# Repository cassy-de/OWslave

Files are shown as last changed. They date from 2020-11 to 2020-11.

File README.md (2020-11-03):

# OWslave
OneWire Slave DIY Module

<p align="center">
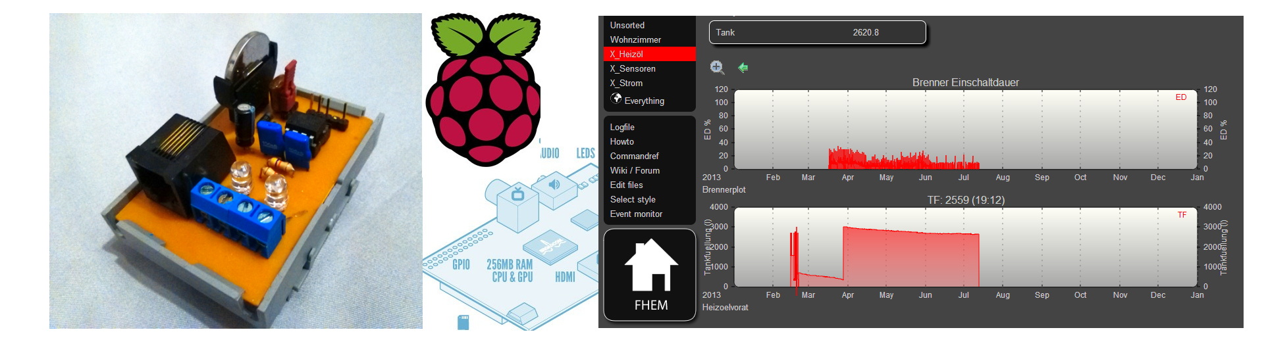
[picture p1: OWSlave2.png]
  
</p>

 ATtiny 25, intern 8MHz
 PB4 als Autoincrement-Counters.A, low-aktiv (Pegel), alle 10 Sekunden ein Count
 PB3 ist abgehängt von Counters.B, dafür machen PB0 und PB1 den I2C-Bus für den SRF02 auf 

 lfuse 62
 hfuse DF
 efuse FF

<p align="center">
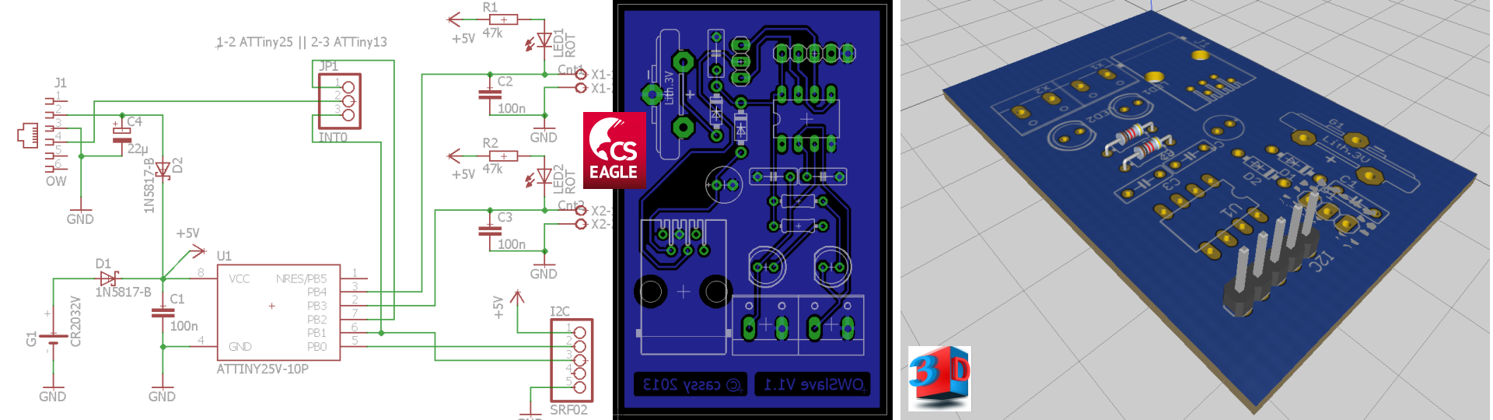
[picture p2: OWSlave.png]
  
</p>

-------------
Zur Firmware:
Die I2C-Libs werden zusätzlich eingebunden, die I2C-Adresse des SRF02 ist fix 0xE0, er wird mit cm als Rückgabewert programmiert. Die Interrupts von
PB3 und PB4 sind disabled, denn PB3 (Counters.B) wird nicht benötigt (ist Messwert des SRF02), und PB4 (Counters.A) wird in der main{} gepollt, dann 10 Sekunden Pause und wieder von vorne, also eigentlich straightforward gelöst. Die I2C-Routine sind atomar gesetzt, dass hier kein IRQ dazwischenfunkt. Somit kann es passieren, dass u.U. der OWFS/OWserver das Device nicht erreicht. Aber lieber in FHEM einen alten Messwert fortschreiben, als einen definitiv falschen eintragen. Achso, in der ISR sind die beiden Increments gelöscht. Und die Extra-Inits für den ATtiny2313 habe ich gleich aus dem Quellcode geschmissen, somit liest es sich etwas leichter.

-------------
OWServer Anzeige:

address 1DA2D984000102F3

counters.ALL 5, 136

counters.A 5

counters.B 136

crc8 F3

family 1D

id A2D984000102

Passt alles soweit, der Brenner lief testweise 55 Sekunden (counters.A ist 5), und bis zum Heizöl sind es  136 cm.

Viel Spass beim Testen.

cassy

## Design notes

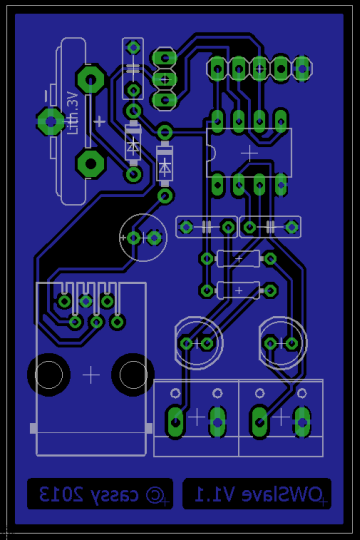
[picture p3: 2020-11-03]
Eagle/Board.PNG

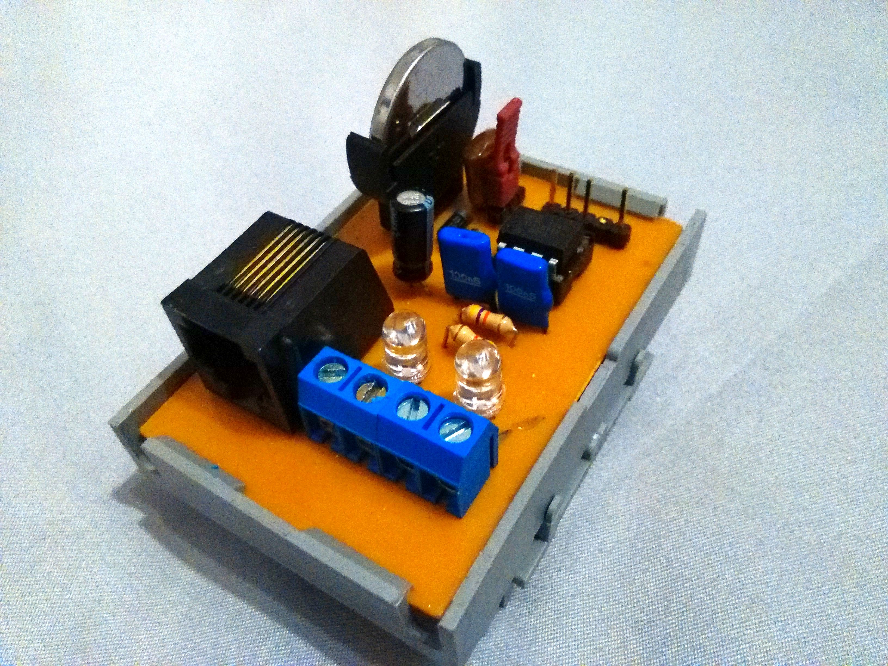
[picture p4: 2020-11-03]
Eagle/Board.jpg

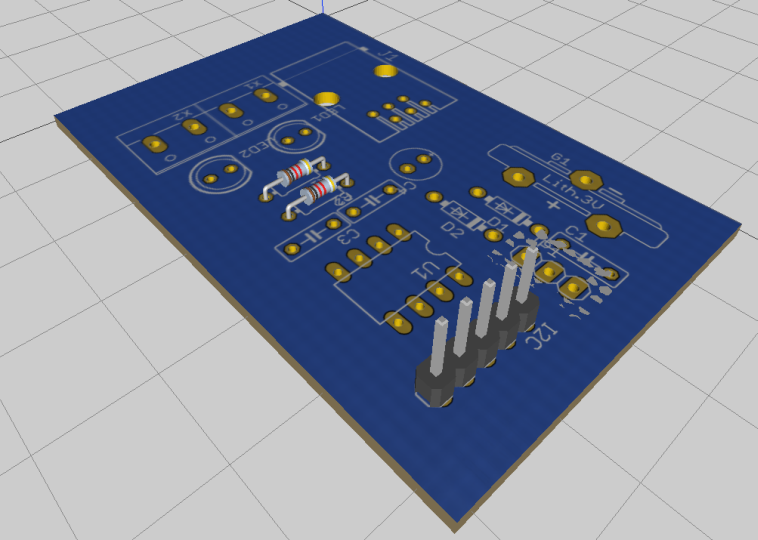
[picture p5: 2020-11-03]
Eagle/Board-3D.PNG

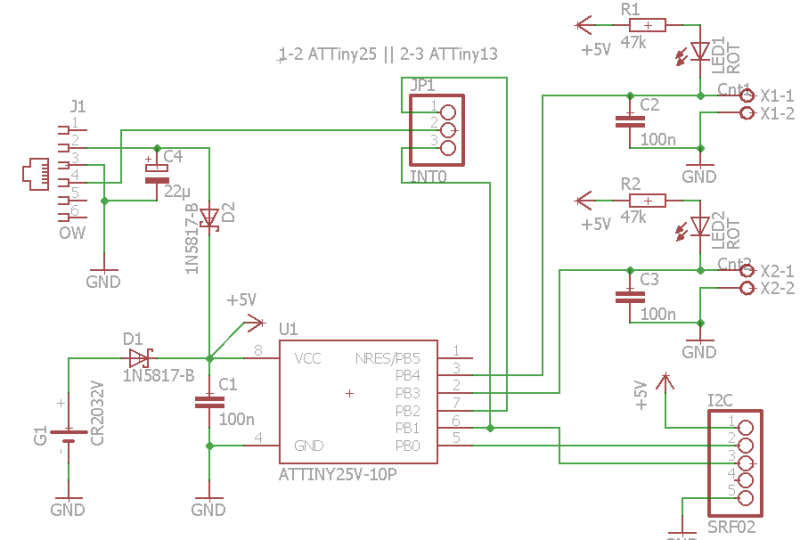
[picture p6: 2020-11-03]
Eagle/Schaltplan.PNG

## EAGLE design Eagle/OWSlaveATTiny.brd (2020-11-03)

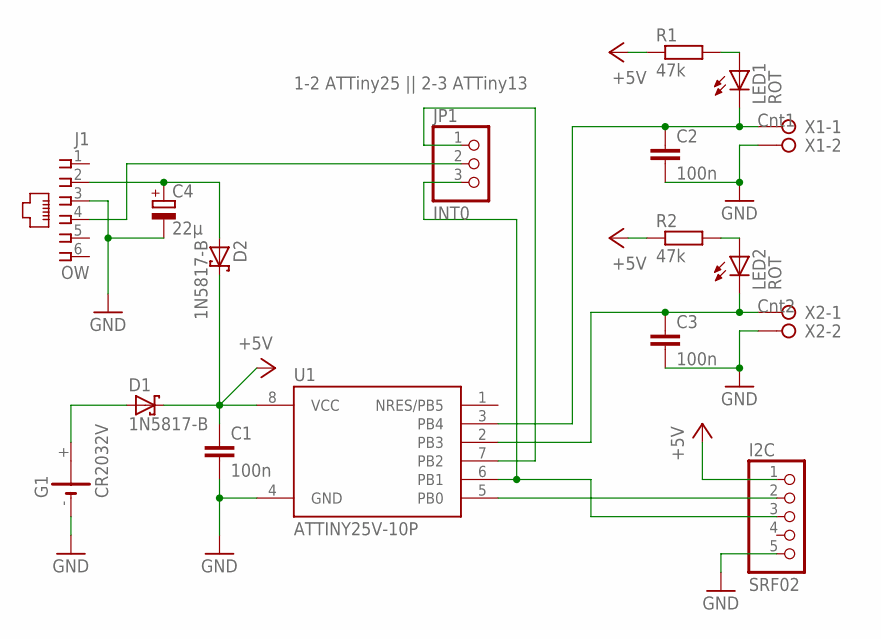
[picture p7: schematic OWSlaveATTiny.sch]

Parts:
C1, C2, C3: 100n; C050-025X075
C4: 22µ; E2,5-6E
D1, D2: 1N5817-B; DO41-7.6
G1: CR2032V
I2C: SRF02; 1X05
J1: OW; 520250-3
JP1: INT0; 1X03
LED1, LED2: ROT; LED5MM
R1, R2: 47k; 0204/7
U1: ATTINY25V-10P; PDIP08_300MIL
X1: Cnt1; W237-132
X2: Cnt2; W237-132

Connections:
+5V: C1.1, D1.C, D2.C, I2C.1, R1.1, R2.1, U1.8 (VCC)
GND: C1.2, C2.2, C3.2, C4.-, G1.-, I2C.5, J1.3, U1.4 (GND), X1.2, X2.2
unnamed: LED1.A, R1.2
unnamed: D1.A, G1.+
unnamed: J1.4, JP1.2
unnamed: C2.1, LED1.K (C), U1.3 (PB4), X1.1
unnamed: C3.1, LED2.K (C), U1.2 (PB3), X2.1
unnamed: I2C.3, JP1.3, U1.6 (PB1)
unnamed: JP1.1, U1.7 (PB2)
unnamed: I2C.2, U1.5 (PB0)
unnamed: C4.+, D2.A, J1.2
unnamed: LED2.A, R2.2

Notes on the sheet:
1-2 ATTiny25 || 2-3 ATTiny13

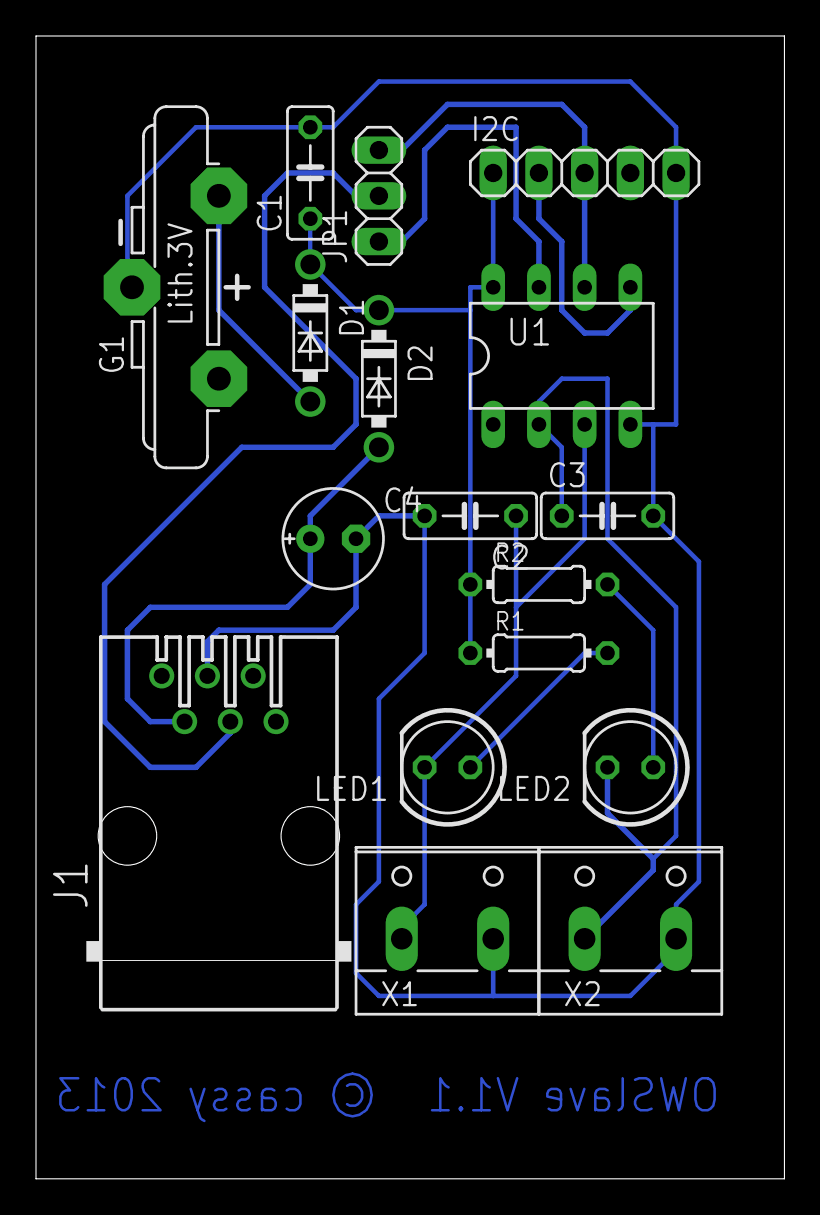
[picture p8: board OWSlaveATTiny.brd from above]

Board: 2 copper layers, 41.6 x 63.5 mm, 17 parts (0 on the bottom side), 12 nets.

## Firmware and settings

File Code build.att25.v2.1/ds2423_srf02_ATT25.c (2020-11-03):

//owdevice - A small 1-Wire emulator for AVR Microcontroller
//
//Copyright (C) 2012  Tobias Mueller mail (at) tobynet.de
//Modification by Christoph A. Straessle 2013 (s. below)
//
//
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
//
//VERSION 1.2 DS2423  for ATTINY2313 and ATTINY25
//Version 2.0 als DS2423 fuer ATtiny25 mit I2C-libs und Anbindung an SRF02 als counters.B
//Version 2.1 als DS2423 fuer ATtiny25 mit Sekunden-Zaehler counter.A, I2C-libs und Anbindung an SRF02 als counters.B
// PB0 - SDA
// PB1 - SCL
// PB2 - OW <- INT0 fixed
// PB3 - ( counters.A) als Gate fuer Counter.A-Sekundenimpulse 
// PB4 - ( counters.B) unused, nun als Ausgang fuer die Impuls-LED

#include <avr/io.h>
#include <avr/interrupt.h>
#define F_CPU 8000000UL
#include <util/delay.h>
#include "i2cmaster.h"

#define SRF02_ADDRESS 0xE0

/* SRF02 - Get Distance in cm. */
unsigned int read_cm(unsigned char address)
{
	unsigned char lowbyte,highbyte;
	unsigned int distance;

	i2c_start_wait(address+I2C_WRITE);
	while (i2c_write(0));
	while (i2c_write(81));
	i2c_stop();

	i2c_start_wait(address+I2C_WRITE);
	while (i2c_write(2));
	i2c_stop();

	_delay_ms(65);
	i2c_start_wait(address+I2C_READ);
	highbyte = i2c_readAck();
	lowbyte = i2c_readNak();
	distance = (highbyte*256)+lowbyte;
	i2c_stop();

	return distance;
} 


#ifdef __AVR_ATtiny25__ 

//LED Pin
#define LED_PORT PORTB //LED Port
#define LED_PIN PINB //LED Pin as number
#define LED_PORTN (1<<PINB3)  //Pin as bit in registers
#define LED_PINN (1<<PINB3)
#define LED_DDR DDRB  //pin direction register
#define LED_EIN OW_DDR|=OW_PINN;OW_PORT&=~OW_PORTN;  //set LED line to low
#define LED_AUS {OW_DDR&=~OW_PINN;}  //set LED pin as input -> LED aus

// OW_PORT Pin 7  - PB2
//OW Pin
#define OW_PORT PORTB //1 Wire Port
#define OW_PIN PINB //1 Wire Pin as number
#define OW_PORTN (1<<PINB2)  //Pin as bit in registers
#define OW_PINN (1<<PINB2)
#define OW_DDR DDRB  //pin direction register
#define SET_LOW OW_DDR|=OW_PINN;OW_PORT&=~OW_PORTN;  //set 1-Wire line to low
#define RESET_LOW {OW_DDR&=~OW_PINN;}  //set 1-Wire pin as input
//Pin interrupt	
#define EN_OWINT {GIMSK|=(1<<INT0);GIFR|=(1<<INTF0);}  //enable interrupt 
#define DIS_OWINT  GIMSK&=~(1<<INT0);  //disable interrupt
#define SET_RISING MCUCR=(1<<ISC01)|(1<<ISC00);  //set interrupt at rising edge
#define SET_FALLING MCUCR=(1<<ISC01); //set interrupt at falling edge
#define CHK_INT_EN (GIMSK&(1<<INT0))==(1<<INT0) //test if interrupt enabled
#define PIN_INT ISR(INT0_vect)  // the interrupt service routine
//Timer Interrupt
#define EN_TIMER {TIMSK |= (1<<TOIE0); TIFR|=(1<<TOV0);} //enable timer interrupt
#define DIS_TIMER TIMSK  &= ~(1<<TOIE0); // disable timer interrupt
#define TCNT_REG TCNT0  //register of timer-counter
#define TIMER_INT ISR(TIM0_OVF_vect) //the timer interrupt service routine


#define OWT_MIN_RESET 51
#define OWT_RESET_PRESENCE 4
#define OWT_PRESENCE 20 
#define OWT_READLINE 3 //for fast master, 4 for slow master and long lines
#define OWT_LOWTIME 3 //for fast master, 4 for slow master and long lines

//Initializations of AVR
#define INIT_AVR CLKPR=(1<<CLKPCE); \
				   CLKPR=0; /*8Mhz*/  \
				   TIMSK=0; \
				   GIMSK=(1<<INT0);  /*set direct GIMSK register*/ \
				   TCCR0B=(1<<CS00)|(1<<CS01); /*8mhz /64 couse 8 bit Timer interrupt every 8us*/

// PINB3 und PB4 werden nun gepollt für die Sekundengate-Zählerfunktion
// somit IRQ-Funktionen nicht benötigt				   
// #define PC_INT_ISR ISR(PCINT0_vect) { /*ATT25 with 0 by PCINT*/ \
//					if (((PINB&(1<<PINB3))==0)&&((istat&(1<<PINB3))==(1<<PINB3))) {	}		\
//					if (((PINB&(1<<PINB4))==0)&&((istat&(1<<PINB4))==(1<<PINB4))) {	Counter1++;	}		\
//					istat=PINB;}	\
//					
// #define INIT_COUNTER_PINS /* Counter Interrupt */\
//						GIMSK|=(1<<PCIE);\
//						PCMSK=(1<<PCINT3)|(1<<PCINT4);	\
//						DDRB &=~((1<<PINB3)|(1<<PINB4)); \
//						istat=PINB;\
					
#endif // __AVR_ATtiny25__ 



//#define _ONE_DEVICE_CMDS_  //Commands for only one device on bus (Not tested)



typedef union {
	volatile uint8_t bytes[13];//={1,1,2,0,0,0,0,0,0,0,0,5,5};
	struct {
		uint16_t addr;
		uint8_t read;
		uint32_t counter;
		uint32_t zero;
		uint16_t crc;
	};
} counterpack_t;
counterpack_t counterpack;
volatile uint16_t scrc; //CRC calculation

volatile uint8_t lastcps;
volatile uint32_t Counter0;
volatile uint32_t Counter1;
volatile uint8_t istat;


volatile uint8_t cbuf; //Input buffer for a command
const uint8_t owid[8]={0x1D, 0xA2, 0xD9, 0x84, 0x00, 0x01, 0x02, 0xF3};    
//set your own ID http://www.tm3d.de/index.php/tools/14-crc8-berechnung
volatile uint8_t bitp;  //pointer to current Byte
volatile uint8_t bytep; //pointer to current Bit

volatile uint8_t mode; //state
volatile uint8_t wmode; //if 0 next bit that send the device is  0
volatile uint8_t actbit; //current
volatile uint8_t srcount; //counter for search rom

//States / Modes
#define OWM_SLEEP 0  //Waiting for next reset pulse
#define OWM_RESET 1  //Reset pulse received 
#define OWM_PRESENCE 2  //sending presence pulse
#define OWM_READ_COMMAND 3 //read 8 bit of command
#define OWM_SEARCH_ROM 4  //SEARCH_ROM algorithms
#define OWM_MATCH_ROM 5  //test number
#define OWM_CHK_RESET 8  //waiting of rising edge from reset pulse
#define OWM_GET_ADRESS 6
#define OWM_READ_MEMORY_COUNTER 7
#define OWM_WRITE_SCRATCHPAD 9
#define OWM_READ_SCRATCHPAD 10

#ifdef _ONE_DEVICE_CMDS_
#define OWM_READ_ROM 50
#endif

//Write a bit after next falling edge from master
//its for sending a zero as soon as possible 
#define OWW_NO_WRITE 2
#define OWW_WRITE_1 1
#define OWW_WRITE_0 0



PIN_INT {
	uint8_t lwmode=wmode;  //let this variables in registers
	uint8_t lmode=mode;
	if ((lwmode==OWW_WRITE_0)) {SET_LOW;lwmode=OWW_NO_WRITE;}    //if necessary set 0-Bit 
	DIS_OWINT; //disable interrupt, only in OWM_SLEEP mode it is active
	switch (lmode) {
		case OWM_SLEEP:  
			TCNT_REG=~(OWT_MIN_RESET);
			EN_OWINT; //other edges ?
			break;
		//start of reading with falling edge from master, reading closed in timer isr
		case OWM_MATCH_ROM:  //falling edge wait for receive 
		case OWM_GET_ADRESS:
		case OWM_READ_COMMAND:
			TCNT_REG=~(OWT_READLINE); //wait a time for reading
			break;
		case OWM_SEARCH_ROM:   //Search algorithm waiting for receive or send
			if (srcount<2) { //this means bit or complement is writing, 
				TCNT_REG=~(OWT_LOWTIME);
			} else 
				TCNT_REG=~(OWT_READLINE);  //init for read answer of master 
			break;
#ifdef _ONE_DEVICE_CMDS_
		case OWM_READ_ROM:
#endif		
		case OWM_READ_MEMORY_COUNTER: //a bit is sending 
			TCNT_REG=~(OWT_LOWTIME);
			break;
		case OWM_CHK_RESET:  //rising edge of reset pulse
			SET_FALLING; 
			TCNT_REG=~(OWT_RESET_PRESENCE);  //waiting for sending presence pulse
			lmode=OWM_RESET;
			break;
	}
	EN_TIMER;
	mode=lmode;
	wmode=lwmode;
	
}			

	

TIMER_INT {
	uint8_t lwmode=wmode; //let this variables in registers
	uint8_t lmode=mode;
	uint8_t lbytep=bytep;
	uint8_t lbitp=bitp;
	uint8_t lsrcount=srcount;
	uint8_t lactbit=actbit;
	uint16_t lscrc=scrc;
	//Ask input line sate 
	uint8_t p=((OW_PIN&OW_PINN)==OW_PINN);  
	//Interrupt still active ?
	if (CHK_INT_EN) {
		//maybe reset pulse
		if (p==0) { 
			lmode=OWM_CHK_RESET;  //wait for rising edge
			SET_RISING; 
		}
		DIS_TIMER;
	} else
	switch (lmode) {
		case OWM_RESET:  //Reset pulse and time after is finished, now go in presence state
			lmode=OWM_PRESENCE;
			SET_LOW;
			TCNT_REG=~(OWT_PRESENCE);
			DIS_OWINT;  //No Pin interrupt necessary only wait for presence is done
			break;
		case OWM_PRESENCE:
			RESET_LOW;  //Presence is done now wait for a command
			lmode=OWM_READ_COMMAND;
			cbuf=0;lbitp=1;  //Command buffer have to set zero, only set bits will write in
			break;
		case OWM_READ_COMMAND:
			if (p) {  //Set bit if line high 
				cbuf|=lbitp;
			} 
			lbitp=(lbitp<<1);
			if (!lbitp) { //8-Bits read
				lbitp=1;
				switch (cbuf) {
					case 0x55:lbytep=0;lmode=OWM_MATCH_ROM;break;
					case 0xF0:  //initialize search rom
						lmode=OWM_SEARCH_ROM;
						lsrcount=0;
						lbytep=0;
						lactbit=(owid[lbytep]&lbitp)==lbitp; //set actual bit
						lwmode=lactbit;  //prepare for writing when next falling edge
						break;
					case 0xA5:
						lmode=OWM_GET_ADRESS; //first the master send an address 
						lbytep=0;lscrc=0x7bc0; //CRC16 of 0xA5
						counterpack.bytes[0]=0;
						break;
#ifdef _ONE_DEVICE_CMDS_
					case 0xCC:
						lbytep=0;cbuf=0;lmode=OWM_READ_COMMAND;break;
					case 0x33:
						lmode=OWM_READ_ROM;
						lbytep=0;	
						break;
#endif											
					default: lmode=OWM_SLEEP;  //all other commands do nothing
				}		
			}			
			break;
		case OWM_SEARCH_ROM:
			RESET_LOW;  //Set low also if nothing send (branch takes time and memory)
			lsrcount++;  //next search rom mode
			switch (lsrcount) {
				case 1:lwmode=!lactbit;  //preparation sending complement
					break;
				case 3:
					if (p!=(lactbit==1)) {  //check master bit
						lmode=OWM_SLEEP;  //not the same go sleep
					} else {
						lbitp=(lbitp<<1);  //prepare next bit
						if (lbitp==0) {
							lbitp=1;
							lbytep++;
							if (lbytep>=8) {
								lmode=OWM_SLEEP;  //all bits processed 
								break;
							}
						}				
						lsrcount=0;
						lactbit=(owid[lbytep]&lbitp)==lbitp;
						lwmode=lactbit;
					}		
					break;			
			}
			break;
		case OWM_MATCH_ROM:
			if (p==((owid[lbytep]&lbitp)==lbitp)) {  //Compare with ID Buffer
				lbitp=(lbitp<<1);
				if (!lbitp) {
					lbytep++;
					lbitp=1;
					if (lbytep>=8) {
						lmode=OWM_READ_COMMAND;  //same? get next command
						
						cbuf=0;
						break;			
					}
				} 
			} else {
				lmode=OWM_SLEEP;
			}
			break;
		case OWM_GET_ADRESS:  
			if (p) { //Get the Address for reading
				counterpack.bytes[lbytep]|=lbitp;
			}  
			//address is part of crc
			if ((lscrc&1)!=p) lscrc=(lscrc>>1)^0xA001; else lscrc >>=1;
			lbitp=(lbitp<<1);
			if (!lbitp) {	
				lbytep++;
				lbitp=1;
				if (lbytep==2) {
					lmode=OWM_READ_MEMORY_COUNTER;
					lactbit=(lbitp&counterpack.bytes[lbytep])==lbitp;
					lwmode=lactbit;
					lsrcount=(counterpack.addr&0xfe0)+0x20-counterpack.addr; 
					//bytes between start and Counter Values, Iam never understanding why so much???
					break;
				} else counterpack.bytes[lbytep]=0;
			}			
			break;	
		case OWM_READ_MEMORY_COUNTER:
			RESET_LOW;
			//CRC16 Calculation
			if ((lscrc&1)!=lactbit) lscrc=(lscrc>>1)^0xA001; else lscrc >>=1;
			p=lactbit;
			lbitp=(lbitp<<1);
			if (!lbitp) {		
				lbytep++;
				lbitp=1;
				if (lbytep==3) {
					lsrcount--;
					if (lsrcount) lbytep--;
					else  {//now copy counter in send buffer
						switch (counterpack.addr&0xFe0) {
						case 0x1E0:
							counterpack.counter=Counter0;
							break;
						case 0x1C0:
							counterpack.counter=Counter1;
							break;
						default: counterpack.counter=0;
						}
					}
				}
				if (lbytep>=13) { //done sending
					lmode=OWM_SLEEP;
					break;			
				}  		 
				if ((lbytep==11)&&(lbitp==1)) { //Send CRC
					counterpack.crc=~lscrc; 
				}			
					 
			}					
			lactbit=(lbitp&counterpack.bytes[lbytep])==lbitp;
			lwmode=lactbit;
			
			break;
#ifdef _ONE_DEVICE_CMDS_	
		case OWM_READ_ROM:
			RESET_LOW;
			lbitp=(lbitp<<1);
			if (!lbitp) {		
				lbytep++;
				lbitp=1;
				if (lbytep>=8) {
					lmode=OWM_SLEEP;
					break;			
				} 
			}					
			lactbit=(lbitp&owid[lbytep])==lbitp;
			lwmode=lactbit;
			break;
#endif		
		}
		if (lmode==OWM_SLEEP) {DIS_TIMER;}
		if (lmode!=OWM_PRESENCE)  { 
			TCNT_REG=~(OWT_MIN_RESET-OWT_READLINE);  //OWT_READLINE around OWT_LOWTIME
			EN_OWINT;
		}
		mode=lmode;
		wmode=lwmode;
		bytep=lbytep;
		bitp=lbitp;
		srcount=lsrcount;
		actbit=lactbit;
		scrc=lscrc;
}



PC_INT_ISR  //for counting  defined for specific device



int main(void) {
	mode=OWM_SLEEP;
	wmode=OWW_NO_WRITE;
	OW_DDR&=~OW_PINN;
	
	uint8_t i;
	for(i=0;i<sizeof(counterpack);i++) counterpack.bytes[i]=0;
	Counter0=0;
	Counter1=0;
	
	SET_FALLING;
	
	INIT_AVR
	DIS_TIMER;
	
	i2c_init();
	
	INIT_COUNTER_PINS

	sei();
	
	while(1)
	{
	// Start	Distance Measurement
	Counter0 = read_cm(SRF02_ADDRESS);
	if ((PINB&(1<<PINB4))==0)	// PB4 als Gate für den Sekundenzähler
		{
		Counter1++;
		LED_EIN;	// PB3 low LED ein
		}
    _delay_ms(500);
	LED_AUS;		// PB3 high LED aus
	_delay_ms(500);
	}
}	

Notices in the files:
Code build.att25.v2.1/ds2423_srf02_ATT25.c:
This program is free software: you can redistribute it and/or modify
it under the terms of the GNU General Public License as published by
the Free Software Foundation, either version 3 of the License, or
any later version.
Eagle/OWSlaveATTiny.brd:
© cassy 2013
